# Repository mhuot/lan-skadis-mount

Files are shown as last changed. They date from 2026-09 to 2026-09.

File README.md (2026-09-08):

# SKÅDIS Bench Frame Mount

Hang an IKEA SKÅDIS pegboard on the slotted DuraFrame uprights of an
Ergotron LAN Organizer 3000. A sheet of hardware-store pegboard works too. No
drilling into the frame, no wall, no rail. The brackets hook into the slots
that are already there.

Grown out of [lan-spool-shelf](https://github.com/mhuot/lan-spool-shelf).
The hook that grips the upright is the one already fit-verified on the real
desk.

## The desk

In the 1990s it felt like every NOC and data center, at least the ones near
me, had furniture from [Ergotron](https://www.ergotron.com/) in
[Eagan, Minnesota](https://en.wikipedia.org/wiki/Eagan,_Minnesota). The desks
matched the look those rooms had and the job they did.

The one I have sat in a data center with a row of computers on it. They ran
the small ISP my employer operated. I picked it up when the company
liquidated, after they were no more. The slotted uprights are the same ones
that held their shelves, which is what makes this project possible without a
drill.

<p align="center">
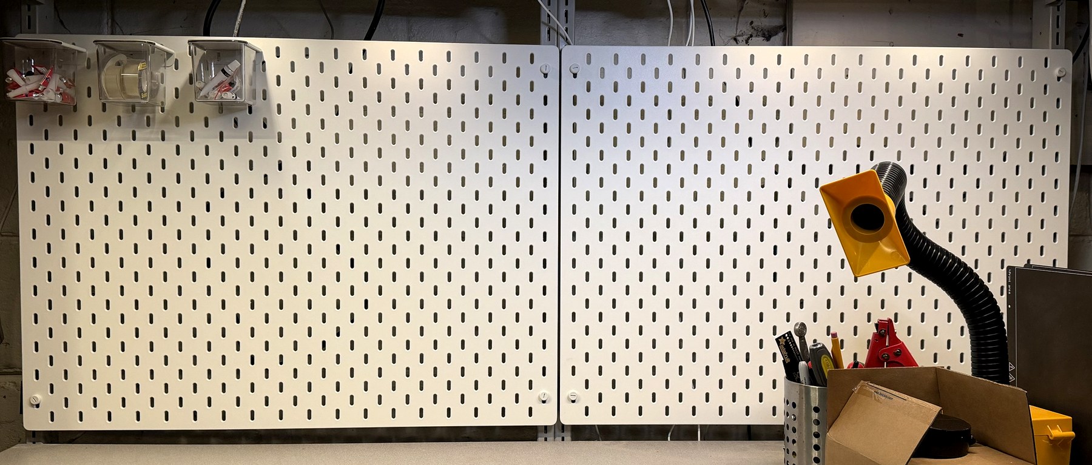
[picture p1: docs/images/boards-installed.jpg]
Two white IKEA SKÅDIS pegboards mounted side by side on the steel uprights of an Ergotron desk frame above a workbench
  
</p>

<p align="center"><em>Two 76 × 56 cm boards on eight brackets. The only fixings you can see are the four decorative screws per board — nothing is drilled into the frame.</em></p>

<p align="center">
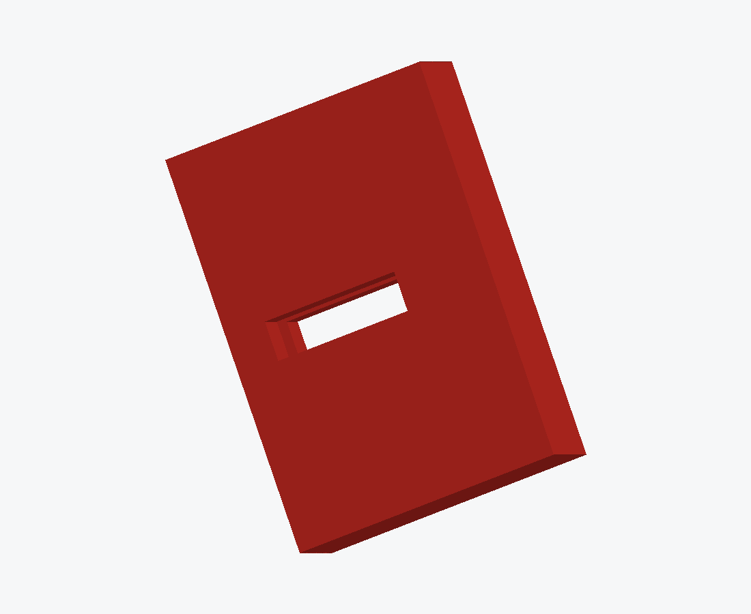
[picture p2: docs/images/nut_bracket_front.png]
Front of the bracket: flat but for the screw slot
  
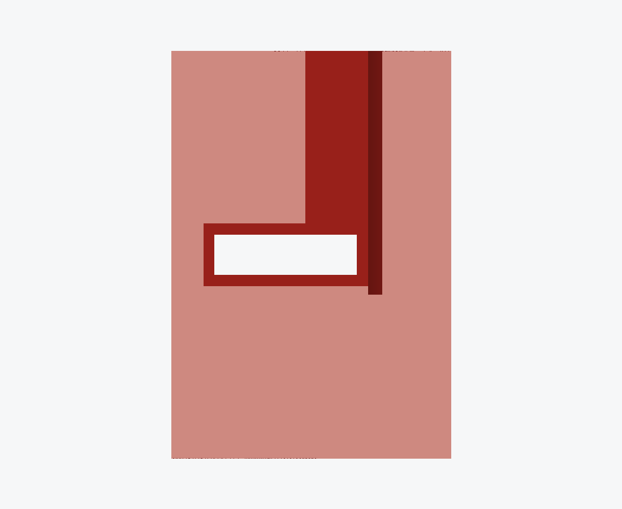
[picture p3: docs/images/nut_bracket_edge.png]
Section along the cavity: the nut drops in from the top edge and slides inboard
  
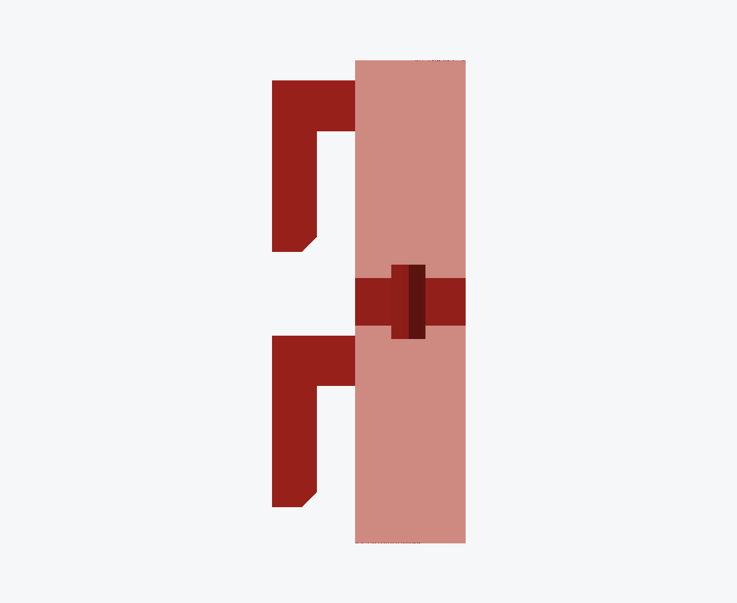
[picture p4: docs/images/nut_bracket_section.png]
Section through the bracket, showing the nut cavity behind a solid wall
  
</p>

## The parts

| Part | Script | State |
| --- | --- | --- |
| **SKÅDIS captured-nut bracket** | `build_skadis_nut_bracket.py` | current design |
| Pegboard bolt-through bracket | `build_pegboard_bracket.py` | for 1/4"-hole pegboard |

### The joint

An **M4 square nut**, measured 7 × 7 × 3 mm, lives in a cavity *inside* the
plate.

- The cavity is enclosed on the board side by **4 mm of solid wall**. The
  board lands on a flat face; nothing but the screw slot breaks it.
- It is **closed at both ends**. The nut drops in through a short vertical
  entry from the plate's **top edge**, at the outboard end of its travel,
  with the bracket in your hand — then slides inboard. To get out again it
  has to be back at that one position *and* rise 20 mm, which gravity never
  does with the bracket hanging. Captured by geometry: nothing to tune,
  nothing to wear.
- The outboard end of the cavity carries a **45° roof** beyond the nut's
  stop, so that end prints unsupported. Without it the slicer grows organic
  support up inside the cavity to hold a 3.4 mm ceiling, and it can never be
  got out.
- It is **12 mm longer than the nut**, and that length is the left-right
  adjustment. Slide, then tighten.
- It is **7.4 mm tall against a 7.0 mm nut**, well under the nut's 9.9 mm
  diagonal, so the nut cannot rotate and the screw can be tightened
  one-handed from the front.
- The IKEA decorative M4 screw goes in through the board, through the wall,
  into the nut, and its tip passes behind the nut in the same slot.
  Tightening pulls the nut **forward onto the wall** and clamps the board
  between the screw head and the plate.

## Measured, not assumed

All taken off the hardware rather than from a datasheet or a library.

| What | Value | Note |
| --- | --- | --- |
| Upright slot | 3/4" tall, 1" pitch, ~1/8" wide | one column per upright |
| Slot column spacing | **735.04 mm** | 28 13/16" between facing slot edges, plus one slot width |
| SKÅDIS board thickness | **6.0 mm** | *not* the 4.6 mm the community libraries quote |
| SKÅDIS slot | 5 × 15 mm on a 40 mm grid | second grid offset 20 mm both ways |
| Decorative M4 screw | **15 mm** | the one IKEA ships |

The nut is a DIN 557 pattern at 7 × 7 × 3 mm. Check yours before printing.
The thin DIN 562 in the same thread size is only 2.2 mm, and a nut that thin
would rattle in this cavity.

## The plate thickness is derived, not chosen

```
plateThickness = screwLength - boardThickness + screwTipClearance
               = 15.0 - 6.0 + 2.0
               = 11.0 mm
```

A 15 mm screw through a 6 mm board leaves 9 mm behind the board with nowhere
to go. A thinner plate would let the tip stand proud of its own back face and
jam against the upright's steel. Change the screw and the plate follows. The
build refuses outright if the tip comes within 0.5 mm of the back face, or if
it would bottom out inside the nut's cavity instead of passing behind it.

At the worst nut position, a bracket's share of a 15 kg loaded board works
out to 0.118 MPa against PETG's ~50 MPa. That is a 400x margin, which is why
the inboard extension carries no stiffening rib.

## Mounting: the two grids do not agree

One channel per bracket, four brackets per board, two per upright. That
moves vertical alignment out of the part and into the assembly, where the
upright's **25.4 mm** pitch has to meet the board's **40 mm** pitch. A screw
has 11 mm of freedom inside its 15 mm slot, so only some spacings work.

**Wider is better.** The two brackets on one upright are what stop the board
rotating, and the moment arm is the distance between them. Take the widest spacing
your board has room for, not the first one that works.

| Brackets apart | Board rows | Mismatch | |
| --- | --- | --- | --- |
| 19 × 25.4 = **482.6 mm** | 12 × 40 = 480 mm | 2.6 mm | ✅ **pick this on a 56 cm board** — lands ~15 mm inside each corner |
| 14 × 25.4 = 355.6 mm | 9 × 40 = 360 mm | 4.4 mm | ✅ |
| 11 × 25.4 = 279.4 mm | 7 × 40 = 280 mm | 0.6 mm | ✅ tightest fit of any |
| 8 × 25.4 = 203.2 mm | 5 × 40 = 200 mm | 3.2 mm | ✅ |
| 3 × 25.4 = 76.2 mm | 2 × 40 = 80 mm | 3.8 mm | ✅ valid, but bunched in the middle |
| 2 × 25.4 = 50.8 mm | 1 × 40 = 40 mm | 10.8 mm | ❌ of 11.0 available |
| 1 × 25.4 = 25.4 mm | 1 × 40 = 40 mm | 14.6 mm | ❌ |

`build_skadis_nut_bracket.py` prints this list on every run. The left and
right brackets are mirrored. Each puts its cavity 7.52 mm toward the centre of
the desk, which is where the board's nearest slot column falls at a 735.04 mm
upright spacing.

## Printing

Lay the bracket on a side face, model Y vertical, so the hook profile is
drawn inside every layer instead of stacked across them. In that orientation
**the cavity and the screw slot need no support at all** (they run along the
build direction), and organic supports grow only under the two hooks.

Put the **inboard edge on the bed**, so the cavity's roofed outboard end is
uppermost. That is `--rotate-x -90` for the **left** bracket and
`--rotate-x 90` for the **right**. The two hands are mirrored, so they do not
share a rotation.

The other way up puts the cavity's flat inboard end on top, where it is a
3.4 mm ceiling. The slicer then fills the cavity with organic support. It sits
exactly where the nut has to slide and you cannot reach it once the part is
off the bed.

- **PETG.** Stresses run 2–5% of yield, so creep is not the concern it is on
  the spool cradle, and the 2.4 mm hook tab is tougher in PETG than in ASA.
  Nothing warps, either.
- 4 perimeters, 40% infill. The stock "STRUCTURAL" profiles are thinner
  than that, and the hooks carry the whole board.
- Organic supports at a **0.25 mm** contact distance. PETG welds itself to
  them at the usual 0.2.
- Supports touch the *side face of the hook tabs* — the face that enters the
  slot. Caliper a tab after cleanup: nominal 2.4 mm, and it has to stay
  under about 2.6 mm to enter a 3.2 mm slot.

About 16 g and an hour per bracket. Four to a plate on a Mini fits at a
14 mm spacing. Below that the brims collide.

## Building the models

Everything is parametric in Fusion 360, driven through its local MCP server.

```sh
python3 scripts/run_in_fusion.py scripts/build_skadis_nut_bracket.py --variant left
python3 scripts/run_in_fusion.py scripts/build_skadis_nut_bracket.py --variant right
python3 scripts/run_in_fusion.py scripts/build_skadis_nut_bracket.py --variant coupon
```

`--variant coupon` is a stub of the real cross-section carrying one cavity.
About 3 g and 13 minutes, and the cheap way to check a nut before committing
to four brackets.

Each run exports `cad/*.step`, `cad/*.f3d` and `exports/*.stl` together, so
they cannot drift apart. Locally, in `.venv`:

```sh
.venv/bin/python scripts/check_stl.py exports/skadis_nut_left.stl 16182
.venv/bin/python scripts/build_web_assets.py       # the GLBs the page loads
.venv/bin/python scripts/render_part.py exports/skadis_nut_left.stl out.png
```

Every user parameter drives geometry, with lengths in mm, angles in degrees
and counts unitless. The build fails if that stops being true, and
`scripts/audit_parameters.py` checks documents that were edited by hand.

## Attribution

This project started from [Skadis to Kallax mount adapter](https://www.printables.com/model/137113-skadis-to-kallax-mount-adapter)
by **WegBier**, licensed CC BY-NC-SA. That is where the idea of mounting to
SKÅDIS with a printed part rather than bolting through it came from. The
licence is incompatible with this repository's MIT licence, so **none of that
model's geometry has ever been reproduced here**. This design shares no
feature with it.

SKÅDIS interface dimensions are measurements of IKEA's product rather than
anyone's authorship. They are cross-checked against
[franpoli/OpenSCADutil](https://github.com/franpoli/OpenSCADutil) and
[TassSinclair/skadis](https://github.com/TassSinclair/skadis), then
re-measured on the board itself.

IKEA, SKÅDIS, Ergotron and DuraFrame are trademarks of their respective
owners. This project is not affiliated with either company.

## Licence

MIT. See [LICENSE](LICENSE).

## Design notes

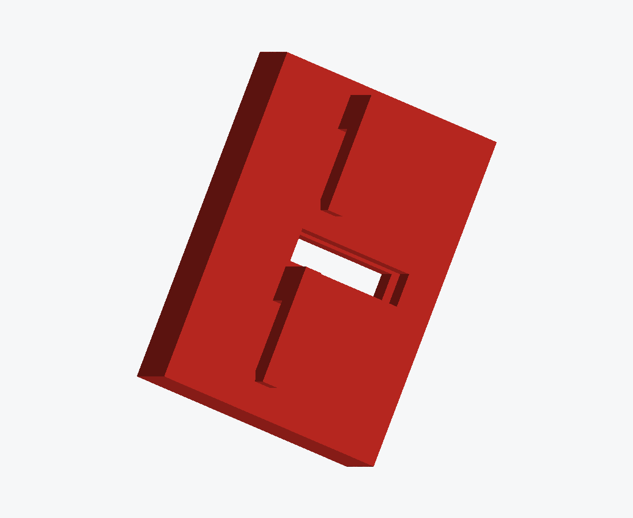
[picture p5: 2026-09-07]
docs/images/nut_bracket_hooks.png

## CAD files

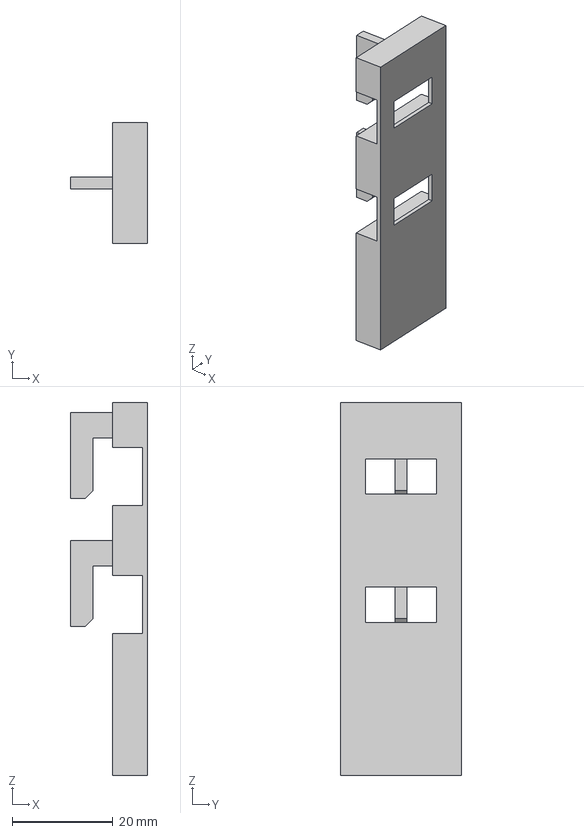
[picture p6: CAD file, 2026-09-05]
cad/pegboard_mount_bracket.step
15.3 x 24.0 x 74.0 mm

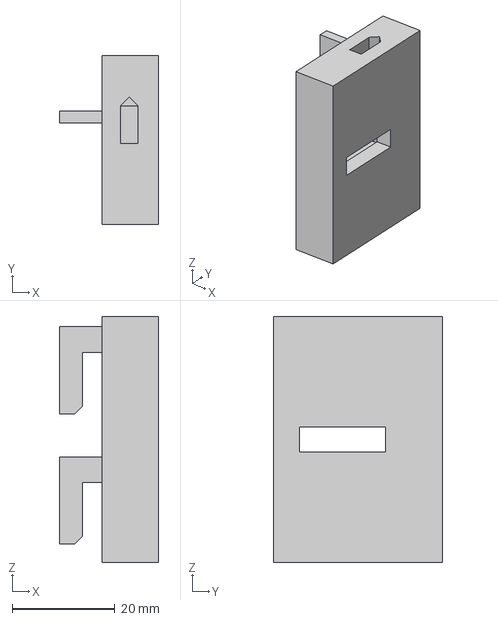
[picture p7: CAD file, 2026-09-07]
cad/skadis_nut_right.step
19.3 x 33.0 x 48.0 mm

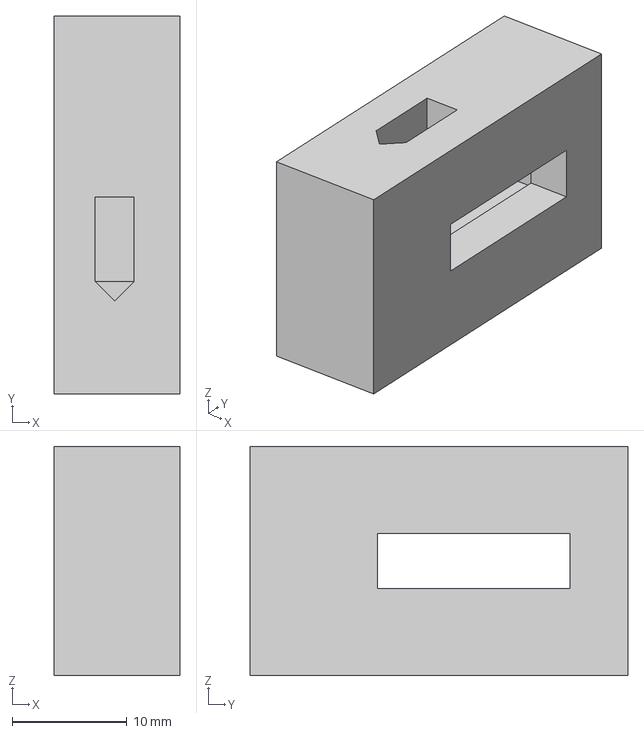
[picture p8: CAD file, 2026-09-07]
cad/skadis_nut_coupon.step
11.0 x 33.0 x 20.0 mm

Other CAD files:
cad/skadis_nut_left.step
cad/pegboard_mount_bracket.f3d
cad/skadis_nut_coupon.f3d
cad/skadis_nut_left.f3d
cad/skadis_nut_right.f3d
exports/pegboard_mount_bracket.stl
exports/skadis_nut_coupon.stl
exports/skadis_nut_left.stl
exports/skadis_nut_right.stl

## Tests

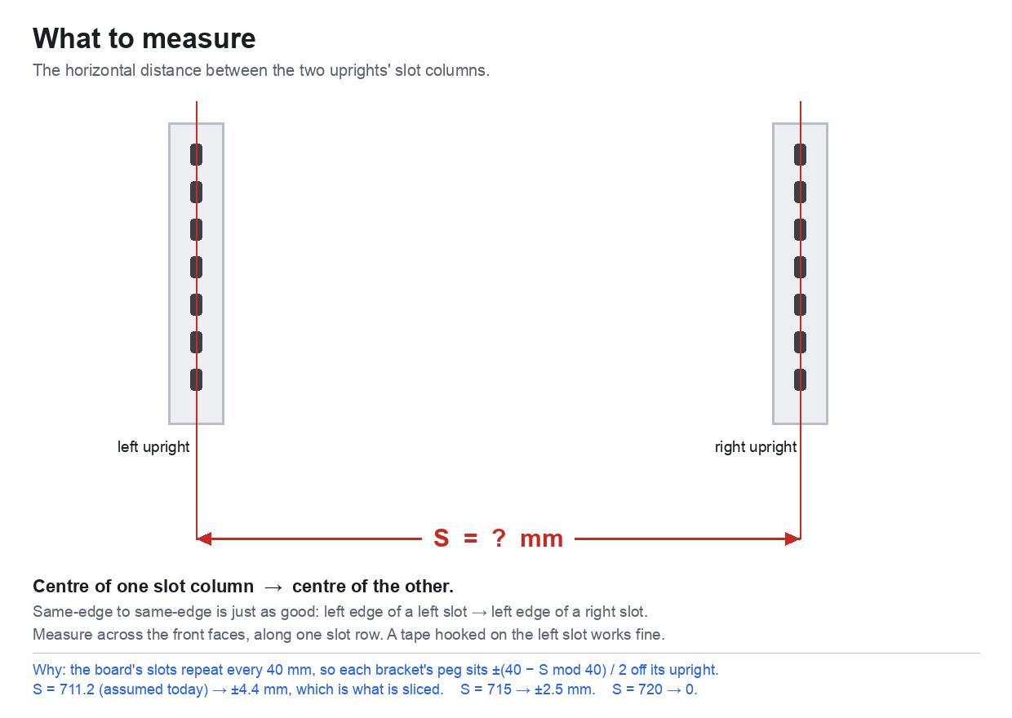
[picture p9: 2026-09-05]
docs/what_to_measure.png

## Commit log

2026-09-04 Pegboard mount bracket: proven hook stack + 1/4-20 nut-track face
    Hooks (verified in lan-spool-shelf) carry a 7 mm plate the pegboard bolts
    to; horizontal bolt slots absorb upright spacing, rear nut tracks keep
    1/4-20 nuts captive and flush. With 1/8-inch board behind a cradle level
    the board face lands at a resting spool's rearmost point - a backstop
    the spools just graze.
    Claude-Session: https://claude.ai/code/session_01FoDmXWCBAcNMibAdUqDKQj
    [pegboard_mount_bracket.f3d, pegboard_mount_bracket.step, pegboard_mount_bracket.stl]
2026-09-05 Parameter-drive the plate, bolt slots and nut tracks, with real units
    The plate and the entire bolt/nut-track group carried parameters that
    drove nothing. Every edge is now dimensioned against them, hookTabWidth
    derives from the measured slotWidth, counts are unitless, and the build
    fails if a parameter drives no geometry or has the wrong unit.
    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
    [pegboard_mount_bracket.f3d, pegboard_mount_bracket.step, pegboard_mount_bracket.stl]
2026-09-05 SKADIS bracket: board hangs on printed pegs, no hardware
    Two upward-opening pegs 40 mm apart carry the board; the slot's top edge
    rests on the peg root and the prong in front stops it tipping out. The
    8.8 mm mismatch between 711.2 mm uprights and the board's 40 mm column
    grid is built into the right-hand variant as pegOffsetY, computed from
    UPRIGHT_SPACING, since a peg has no adjustment.
    Credit: inspired by WegBier's 'Skadis to Kallax mount adapter'
    (printables.com/model/137113), CC BY-NC-SA. That licence is incompatible
    with this repo's MIT, so none of its geometry is reproduced — the peg is
    implemented from published SKADIS interface dimensions cross-checked
    against two independent Open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
    [skadis_bracket_left.f3d, skadis_bracket_left.step, skadis_bracket_left.stl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]
2026-09-05 Round the SKADIS peg: prong lead-in chamfer and root fillets
    1.2 mm chamfer on the prong's top outer corner, because the board is
    lowered onto these pegs blind with the prong hidden behind it — the same
    failure mode the first slot gauge had on the upright, fixed the same way.
    1 mm fillet where each root meets the plate, top and bottom only: the top
    one is where the board's slot edge bears, and a sharp printed corner
    embosses the panel. Sides stay sharp deliberately, since the root is
    4.8 mm in a 5 mm slot and a side fillet would stop the board sitting
    flush.
    Also corrects the print orientation in the README. It said plate-flat,
    which stands each peg on a layer bond with the board's weight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
    [skadis_bracket_left.f3d, skadis_bracket_left.step, skadis_bracket_left.stl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]
2026-09-05 Move the peg fillet to the bearing edges, and stop trusting saveAs
    The fillet was on the root/plate junction edges — the tension side of the
    cantilever, which sounded right and was useless: at ~4 MPa of ~40 strength
    was never the constraint, and those edges sit inside the slot's void where
    the board never touches them. The user moved it in the document to the
    root's top-face side edges, which is where the board's slot edge actually
    lands and what it slides past on the way down, at hookLipChamfer's 1.5 mm.
    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
    [skadis_bracket_left.f3d, skadis_bracket_left.step, skadis_bracket_left.stl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]
2026-09-05 Shift the board 6 mm left, shorten the peg, lower the prong rise
    PEG_OFFSET_OVERRIDE = -6.0 makes the offset signed and usable: negative
    moves the pegs, and the board with them, to the left. Prong thickness
    2.0 -> 1.0 (peg protrudes 5.8 mm instead of 6.8) and prong rise 8 -> 7 mm,
    so the silhouette is 11 mm in a 15 mm slot and the board needs 4 mm of
    lift to release instead of 3.
    Two guards added, both for faults that would have built silently: a peg
    offset that walks off the plate (the +8.8 mm right-hand variant already
    did, with no material either side of the peg), and a lead-in chamfer
    deeper than the prong it is cut into, which 1.2 mm into a 1.0 mm prong
    would have been.
    Co-Authored-By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
    [skadis_bracket_left.f3d, skadis_bracket_left.step, skadis_bracket_left.stl]
2026-09-05 Derive the right peg offset from the left, not from zero
    Only the difference between the two offsets matters: the pegs must land on
    board columns a whole number of pitches apart while the brackets are pinned
    to uprights 711.2 mm apart. Hard-coding the left at zero and loading the
    whole +8.8 mm correction onto the right is what walked its peg off a 24 mm
    plate. With the left placed where the board should sit (-6.5 mm), the right
    falls out at +2.3 mm and both fit with room to spare — verified in the
    meshes, and the engaged columns land exactly 720.0 mm = 18 x 40 apart.
    Note the correction moves the pegs APART, not together: 711.2 has to grow
    to 720. Pulling them toward each other targets 68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
    [skadis_bracket_left.f3d, skadis_bracket_left.step, skadis_bracket_left.stl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]
2026-09-05 Split the grid correction evenly: mirrored brackets, equal peg gaps
    Only the difference between the two peg offsets is fixed by the board's
    40 mm column grid; how it is split is free. Splitting it in half gives
    -4.4 / +4.4, a mirrored pair with an equal 5.20 mm gap from each peg to
    its outer plate edge, verified in the exported meshes. The engaged columns
    still land 720.0 mm = 18 x 40 apart.
    The previous -6.5 / +2.3 satisfied the grid too, but put one peg 3.1 mm
    from an edge and the other 7.3 mm, which is the asymmetry the user spotted
    in the sliced files. BOARD_SHIFT now slides the whole board along the desk
    without breaking the symmetry, replacing the old left-anchored offset.
    Co-Authore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
    [skadis_bracket_left.f3d, skadis_bracket_left.step, skadis_bracket_left.stl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]
2026-09-05 Use the measured upright spacing: 735.04 mm, pegs move together
    Measured 28 13/16" (731.84 mm) between the facing edges of the two slot
    columns; centre-to-centre is that plus one slot width = 735.04 mm. The old
    711.2 mm was a nominal 28 inches and 23.8 mm wrong — most of a slot column.
    That flips the correction's direction as well as its size: 735.04 sits
    15.04 mm past an 18-column span, so the pegs now pull TOWARD each other by
    7.52 mm apiece instead of pushing apart by 4.4. Verified in the meshes,
    peg-to-peg 720.00 mm = 18 x 40 exactly, and still a mirrored pair with
    equal 2.08 mm gaps.
    2.08 mm of plate beside each peg is thin but passes the edge-margin check;
    widening the plate past 2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
    [skadis_bracket_left.f3d, skadis_bracket_left.step, skadis_bracket_left.stl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]
2026-09-05 Grow the plate inboard, where the peg crowds the edge
    The measured spacing pulls both pegs toward the middle of the desk, so the
    inboard edge is the one they crowd — 2.08 mm of plate beside a peg. The
    plate now extends 4 mm on that side only: hooks stay centred on the
    upright's slot column (verified at Y 0.00 in both meshes), the outboard
    edge is unmoved, and the extra material goes into the gap between the
    uprights where nothing else lives. Peg gap 2.08 -> 6.08 mm.
    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
    [skadis_bracket_left.f3d, skadis_bracket_left.step, skadis_bracket_left.stl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]
2026-09-06 Fold in the hand edit: pegClearance, narrower peg, thicker prong
    From SKADIS Bracket Left v6 'User Saved': a new pegClearance parameter
    driving the peg's width fit (0.3 total, so 4.70 mm in a 5.00 mm slot), and
    pegProngThickness back to 2.0 mm. Rebuilt volume 9905 mm^3 matches the
    document exactly.
    The edit also routed pegRootLength through pegClearance. Kept the value but
    split the parameter: pegClearance is a sliding fit across the slot,
    pegRootProud is a standoff past the board's front face. Sharing one would
    mean loosening a tight peg also lets the board rattle front-to-back, since
    one subtracts from the peg and the other adds to it. Both default to 0.3,
    so the geometry is identical eit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
    [skadis_bracket_left.f3d, skadis_bracket_left.step, skadis_bracket_left.stl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]
2026-09-06 Restore the peg root standoff to 0.2 mm
    pegRootProud goes back to what it was before the hand edit routed it
    through pegClearance: root 4.80 mm through a 4.60 mm board, 0.20 mm proud.
    pegClearance stays at 0.3 driving the peg's width fit, which was the
    deliberate part of that edit. Volume 9905 -> 9901 mm^3.
    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
    [skadis_bracket_left.f3d, skadis_bracket_left.step, skadis_bracket_left.stl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]
2026-09-06 Record why the peg clearance and prong thickness are what they are
    Both came from a printed part in a real board: too tight left-to-right in
    the slot (clearance 0.2 -> 0.3, peg 4.70 in a 5.00 slot) and a prong that
    bent under a hand push at 1.0 mm.
    The prong is the member that stops the board tipping out, loaded in bending
    over its 7 mm rise: at 1.0 mm its section modulus is 0.78 mm^3, roughly
    90 MPa at only 10 N. It was 2.0 until I took a requested millimetre off it
    rather than off the root, which is over-strength at ~4 MPa. Comment added
    so the next 'shorten the peg' takes it from the right place.
    Claude-Session: https://claude.ai/cod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
2026-09-06 Fold in the prong front fillet from document v9
    A 1 mm round on the two vertical corners of each prong's front face — the
    outermost surface of the bracket and the one a hand meets when pressing the
    board home. Added by hand in SKADIS Bracket Left v9; rebuilt volume
    9892 mm^3 matches that document exactly, and the right variant now carries
    it too, which the hand edit could not.
    Driven by pegProngFrontFillet rather than the literal 1 mm it was created
    with, and the edge selection asserts it finds exactly 2 x pegRows edges so
    a geometry change cannot silently skip them.
    Claude-Session: https://claude.ai/code/session_01FoDmXWCBAcNMibAdUqD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
    [skadis_bracket_left.f3d, skadis_bracket_left.step, skadis_bracket_left.stl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]
2026-09-06 Bring the docs up to the built and validated design
    The SKADIS section still described the pre-measurement design: nominal
    711.2 mm uprights, an 8.8 mm correction loaded entirely onto the right
    bracket, a 24 mm plate, a 1.2 mm prong chamfer and a root/plate fillet that
    was moved months of iterations ago. All of that is now what was actually
    built and hung on a board: measured 735.04 mm centres, mirrored +/-7.52 mm
    offsets pulling inboard, a 28 mm plate extended inboard only, and the three
    roundings that exist.
    Also records why the numbers are what they are — the too-tight peg that set
    pegClearance, the prong that bent at 1.0 mm — and that the SKADIS variant
    is the one in use.
    Co-Author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
    [skadis_two_sets.stl]
2026-09-06 Add the nut-channel SKADIS bracket: adjustable, and sized to a 15 mm screw
    The peg bracket has no adjustment anywhere. Four rigid posts must enter
    four slots at once, so the upright measurement, print shrinkage and the
    board's tolerance all land on whoever is holding the board; measured 3-5 mm
    out left to right on 2026-09-06 with nothing to turn.
    This replaces the peg with a DIN 562 M4 square nut in a horizontal channel.
    The nut feeds edgewise through a SKADIS slot, turns flat, and drops into the
    channel; the channel is 12 mm longer than the nut, and that length is the
    adjustment. It is 7.4 mm tall against a 7.0 mm nut, so the nut cannot rotate
    and the IKEA decorative screw can be tightened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
    [skadis_nut_coupon.f3d, skadis_nut_coupon.step, skadis_nut_coupon.stl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]
2026-09-06 One nut channel per bracket, and derive the plate height from it
    A board hangs on four of these, two per upright, so one channel each is
    already four screws in a rectangle. A second channel on the same bracket
    adds a constraint rather than strength: the two rows are pinned 40 mm apart
    in the print with no way to take up error between them, which is the same
    trap the pegs fell into one axis over.
    Moving that adjustment into the assembly means the two grids have to be
    reconciled by hand, so the build now prints the spacings that work. The
    upright is on a 25.4 mm pitch and the board on 40 mm, and a screw has 11 mm
    of freedom inside its slot: stack the brackets 3 hook pitches apart (76.2 mm
    aga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
    [skadis_nut_left.f3d, skadis_nut_left.step, skadis_nut_left.stl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]
2026-09-07 Rename to lan-skadis-mount, add the licence it claimed, and a Pages site
    The repo argued in a source comment that WegBier's CC BY-NC-SA licence is
    "incompatible with this repository's MIT licence" while carrying no licence
    file at all. Adds MIT. Also drops the tracked .DS_Store.
    lan-pegboard-mount stopped describing the contents some time ago: three
    designs live here and two of them are SKADIS. PROJECT_DIR in every build
    script follows the directory. The Fusion cloud project keeps its old name
    on purpose -- FUSION_PROJECT_NAME has to match what is actually in the
    cloud, and renaming one without the other silently creates a second project.
    The README was two stacked introductions, one of th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
    [skadis_one_pair.stl, skadis_one_set.stl]
2026-09-07 Untrack the merged multi-part print plates
    skadis_one_pair, skadis_one_set and skadis_two_sets are slicer plates, not
    parts: several brackets merged into one STL to fill a build plate. No script
    in this repo produces them, so they cannot be regenerated, and they carry
    the superseded peg design. Keeping them would ship a file nobody can rebuild
    and nobody should print.
    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
    [skadis_one_pair.stl, skadis_one_set.stl, skadis_two_sets.stl]
2026-09-07 Capture the nut inside the plate, and delete the peg design
    The nut fits the channel, so the size is confirmed. What was wrong was the
    channel: open into the face the board lands on. That meant the nut had to be
    posted through a board slot with the board already hanging, the joint clamped
    board-to-nut instead of board-to-plate, and the board rested on four nuts
    rather than flat on four plates.
    The cavity is now enclosed by a 3 mm wall on the board side and breaks out of
    the plate's outboard edge only, so the nut slides in from the side with the
    bracket in your hand. Tightening pulls it forward onto the wall, which makes
    the joint an ordinary clamped bolt. The screw hole runs the full thickn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
    [skadis_bracket_left.f3d, skadis_bracket_left.step, skadis_bracket_left.stl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]
2026-09-07 Thicken the nut wall to 4 mm
    The wall is what stops the screw pulling the nut through the plate, and it
    spans the cavity's full 7.4 mm height. 3 mm of ASA is fine at hand-tight and
    not obviously fine if someone leans on a driver, so it goes to 4.
    Free, structurally: the plate stays 11.0 mm and the cavity just moves 1 mm
    back, leaving 4.5 mm of plate behind it instead of 5.5. The screw tip still
    stops at x=2.0, now 2.5 mm clear of the cavity rather than 3.5. Volume is
    unchanged at 16651 mm3 -- the cavity moved, it did not grow.
    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
    [skadis_nut_coupon.f3d, skadis_nut_coupon.step, skadis_nut_coupon.stl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]
2026-09-07 Print the cavity mouth UP, not down: the blind end is the overhang
    Mouth-down is the intuitive orientation and it is wrong. The cavity opens at
    the bed and prints as a clean vertical channel, which is exactly what makes
    it look right -- but the blind end is then at the top, its ceiling is a
    horizontal overhang, and the slicer packs the whole cavity with organic
    support that cannot be removed and would stop the nut sliding.
    Sliced both ways on the left bracket: supports reach z 29.0 mouth-down and
    z 21.6 mouth-up, where 21.6 is the hooks and nothing else. So the INBOARD
    edge goes on the bed: --rotate-x -90 for the left, --rotate-x 90 for the
    right. That is the opposite of what the previous c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
2026-09-07 Fix the print orientation on the site too
    The previous commit updated README.md and CLAUDE.md but its site edit did
    not match and was silently skipped, leaving the live page telling people to
    print the cavity mouth-down.
    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
2026-09-07 Rebuild the site around a drawing of the joint, and drop the history
    The README's design history is gone: what the part replaced is git's job, not
    a reader's. The site keeps none of it either -- the page now argues for the
    joint on its own terms rather than by contrast with two designs nobody can
    download.
    The page is rebuilt rather than restyled. The thing worth showing is a joint
    whose whole point is that you cannot see it from outside, so the centrepiece
    is a scaled cross-section at the screw axis: upright face metal, the 11 mm
    plate, the cavity, the nut inside it, the 4 mm wall, the board, the screw.
    Numbered callouts with a legend beside them, rather than labels crammed into
    the drawin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
2026-09-07 Spread the brackets to the board's corners, and say that wider is better
    The viewer had all four brackets 76.2 mm apart in a band across the middle of
    the board, because 3 hook pitches was the first valid spacing the search
    found and nothing anywhere said to prefer a wider one. That is backwards: the
    two brackets on an upright are what stop the board rotating, and the spacing
    between them is the moment arm.
    Searching to 20 pitches instead of 9 turns up three more: 11 (279.4 vs 280,
    off 0.6 -- the tightest fit of any), 14 (355.6 vs 360) and 19 (482.6 vs 480,
    off 2.6). On a 56 cm board 19 pitches lands the brackets about 15 mm inside
    each corner, so that is what the assembly model now shows a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
    [skadis_nut_left.f3d, skadis_nut_left.step]
2026-09-07 Stamp the page's assets with a content hash
    The corrected assembly model was on the server and correct -- brackets
    482.6 mm apart, 17 mm inside each edge of the board -- and a phone that had
    loaded the page earlier still rendered them bunched in the middle. Pages
    caches models and images hard, the HTML beside them was current, and nothing
    about the page looked stale, so there was no signal that anything was wrong.
    scripts/stamp_assets.py rewrites every local src/href in docs/index.html as
    ?v=<first 8 of the file's SHA-256>. The URL then changes exactly when the
    bytes change and stays put when they do not, so ordinary caching still works.
    Idempotent; run it after build_web_assets.py or rende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
2026-09-07 The nut is 7 x 7 x 3, not 2.2 thick: deepen the cavity to suit
    Measured 2026-09-07. That is a DIN 557 pattern square nut, not the thin
    DIN 562 these were built around. The open channel hid the error completely --
    a pocket facing the board does not care how thick the nut is, and the nut
    "fit" it -- so the mistake only surfaced once the cavity was enclosed, where
    0.8 mm too shallow means it will not close at all.
    Cavity depth goes 2.5 -> 3.4 and its back face 4.5 -> 3.6, leaving the screw
    tip 1.6 mm clear instead of 2.5 and engaging 3.0 mm of thread instead of 2.2.
    Depth clearance is deliberately the loosest of the three at 0.4: the screw
    pulls the nut forward onto the wall, so a cavity deepe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
    [skadis_nut_coupon.f3d, skadis_nut_coupon.step, skadis_nut_coupon.stl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]
2026-09-07 Capture the nut from the top edge, and roof the cavity so it prints clean
    The mouth in the outboard edge let the nut slide straight back out with the
    bracket in the hand. A tooth at the mouth was the obvious fix and the wrong
    one: nothing in that joint is compliant, so a rigid bump would shave off in
    PETG within a few insertions and put the fit at the mercy of first-layer
    squish. Instead the cavity is closed at both ends and the nut drops in
    through a short vertical entry from the plate's top edge at the outboard end
    of its travel. To get out it has to be back at that one position and rise
    20 mm, which gravity never does with the bracket hanging. Captured by
    geometry, with nothing to tune an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
    [skadis_nut_coupon.f3d, skadis_nut_coupon.step, skadis_nut_coupon.stl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]
2026-09-07 Finish the top-entry docs: site intro and the stale Printing section
    The site's joint intro still said the nut slides in from the outboard edge,
    and CLAUDE.md's Printing section turned out to be the original pre-cavity
    text -- rotate-x 90 for both hands, 'nut channel', ASA -- which every later
    edit had missed because it patched a different passage. Rewritten outright.
    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
2026-09-07 Section renders that show the void: depth fog and a tinted cap
    Flat orthographic shading gives a hole whose floor is parallel to the face
    around it exactly the tone of that face, so a section along the cavity
    showed a plain red rectangle -- 20 mm of entry slot, gone. Cut faces are now
    tinted and everything is darkened with depth, so the cavity, the entry rising
    from its outboard end and the roof read as the inverted L they are.
    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
2026-09-07 Add a plate builder, because the two hands cannot share a rotation
    The inboard edge goes on the bed, which is --rotate-x -90 for the left
    bracket and +90 for the right. PrusaSlicer's --rotate-x is global, so a plate
    holding one of each cannot be sliced from the part STLs at all: whichever
    hand loses puts its cavity end uppermost, and the slicer packs that cavity
    with organic support that can never be removed.
    scripts/build_plate.py bakes each hand's rotation into the mesh, drops it on
    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
2026-09-08 Lead with the built thing: two boards, installed, on the desk
    Every image on the site was a render or a model, which is a strange way to
    present a design whose whole claim is that it hangs on a desk frame without
    drilling into it. The hero is now a photograph of both boards up.
    Cropped to the boards from a wider frame -- the original had a busy shelf
    underside across the top third and most of a workbench down the right -- and
    lifted slightly in brightness and contrast, which is enough to make the eight
    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
2026-09-08 Say brackets per board in the lede, now the photo shows two
    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
2026-09-08 Cut the process narrative from the site and README
    "Every guess in this project was wrong" is a heading about how the project
    went, not about the part. A reader wants to know which two numbers set the
    plate thickness; that the author got them wrong first is not their problem.
    It becomes "Two measurements set the whole part".
    Same register, same treatment, elsewhere:
    - "neither did the two designs before this one" -- references models that
    are not in the repo and cannot be downloaded
    - "not the thin DIN 562 first assumed" -> "not the thin DIN 562, which is
    2.2 mm", which is the part that helps someone buying nuts
    - "so it cannot get lost in a README nobody rereads" -- an aside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
2026-09-08 Rewrite the page and README in Mike's voice
    Applies the write-like-mike guide, which is now installed as a skill at
    ~/.claude/skills/write-like-mike from github.com/mhuot/write-like-mike.
    The guide's stated punctuation rules are no em-dashes, no colons and no
    semicolons, and it says to follow the stated rules over the older samples
    that break them. The page had 13 em-dashes, 6 semicolons and 3 prose colons,
    nearly all of them joining two sentences that read better apart. "No
    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
2026-09-08 Add where the desk came from
    Mike's words, tidied to the voice guide. Ergotron of Eagan, Minnesota was
    what NOCs and data centers near him ran on in the 1990s. This one held a row
    of computers that ran his employer's small ISP, and he bought it at the
    liquidation after the company folded. Links go to ergotron.com and the Eagan
    Wikipedia page, since Ergotron has no Wikipedia article to point at.
    Sits between the stats strip and the assembly on the page, and gets a "The
    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
